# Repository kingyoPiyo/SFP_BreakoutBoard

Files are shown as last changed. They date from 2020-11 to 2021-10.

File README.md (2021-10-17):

# SFP_BreakoutBoard
KiCad とプリント基板発注練習用に作成した SFP 用の Breakout Board です。身近にある Type-C ケーブルから給電可能となるように仕上げてみました。取り付け穴位置は秋月電子のCタイプ基板に揃えているためスタック可能です。  
性能をテストできる機材を持ち合わせていないので信号品質等の詳細はスペック不明ですが、SFP → SMA → SFP 接続時に 1Gbps および 10Gbps で送受信可能なことを確認しています。  
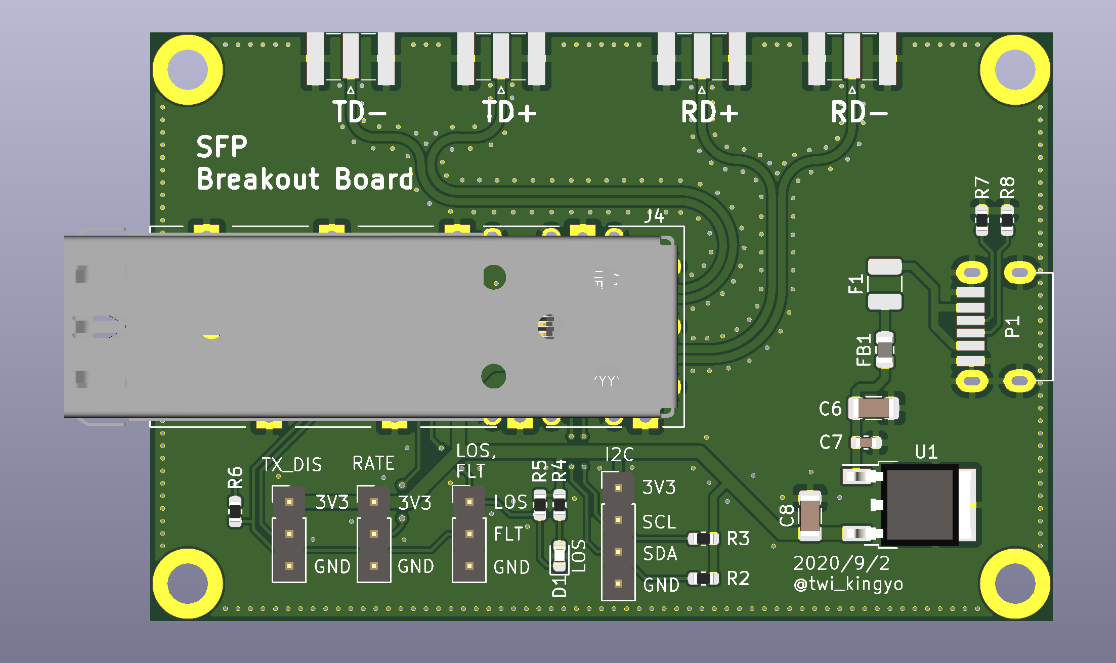
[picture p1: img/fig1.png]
  
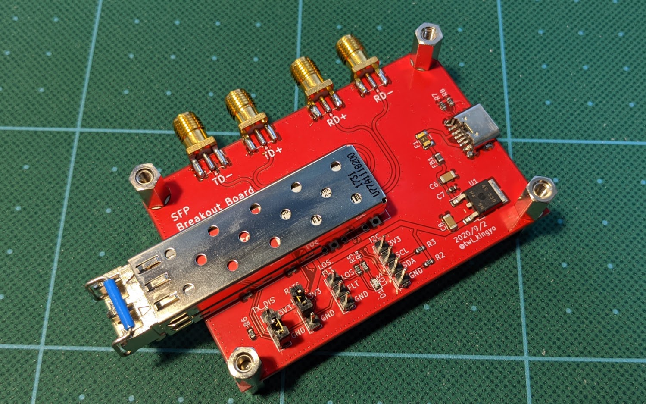
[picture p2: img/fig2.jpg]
  

# 開発環境
- KiCad Version 5.1.6
- RF-tools-KICAD https://github.com/easyw/RF-tools-KiCAD

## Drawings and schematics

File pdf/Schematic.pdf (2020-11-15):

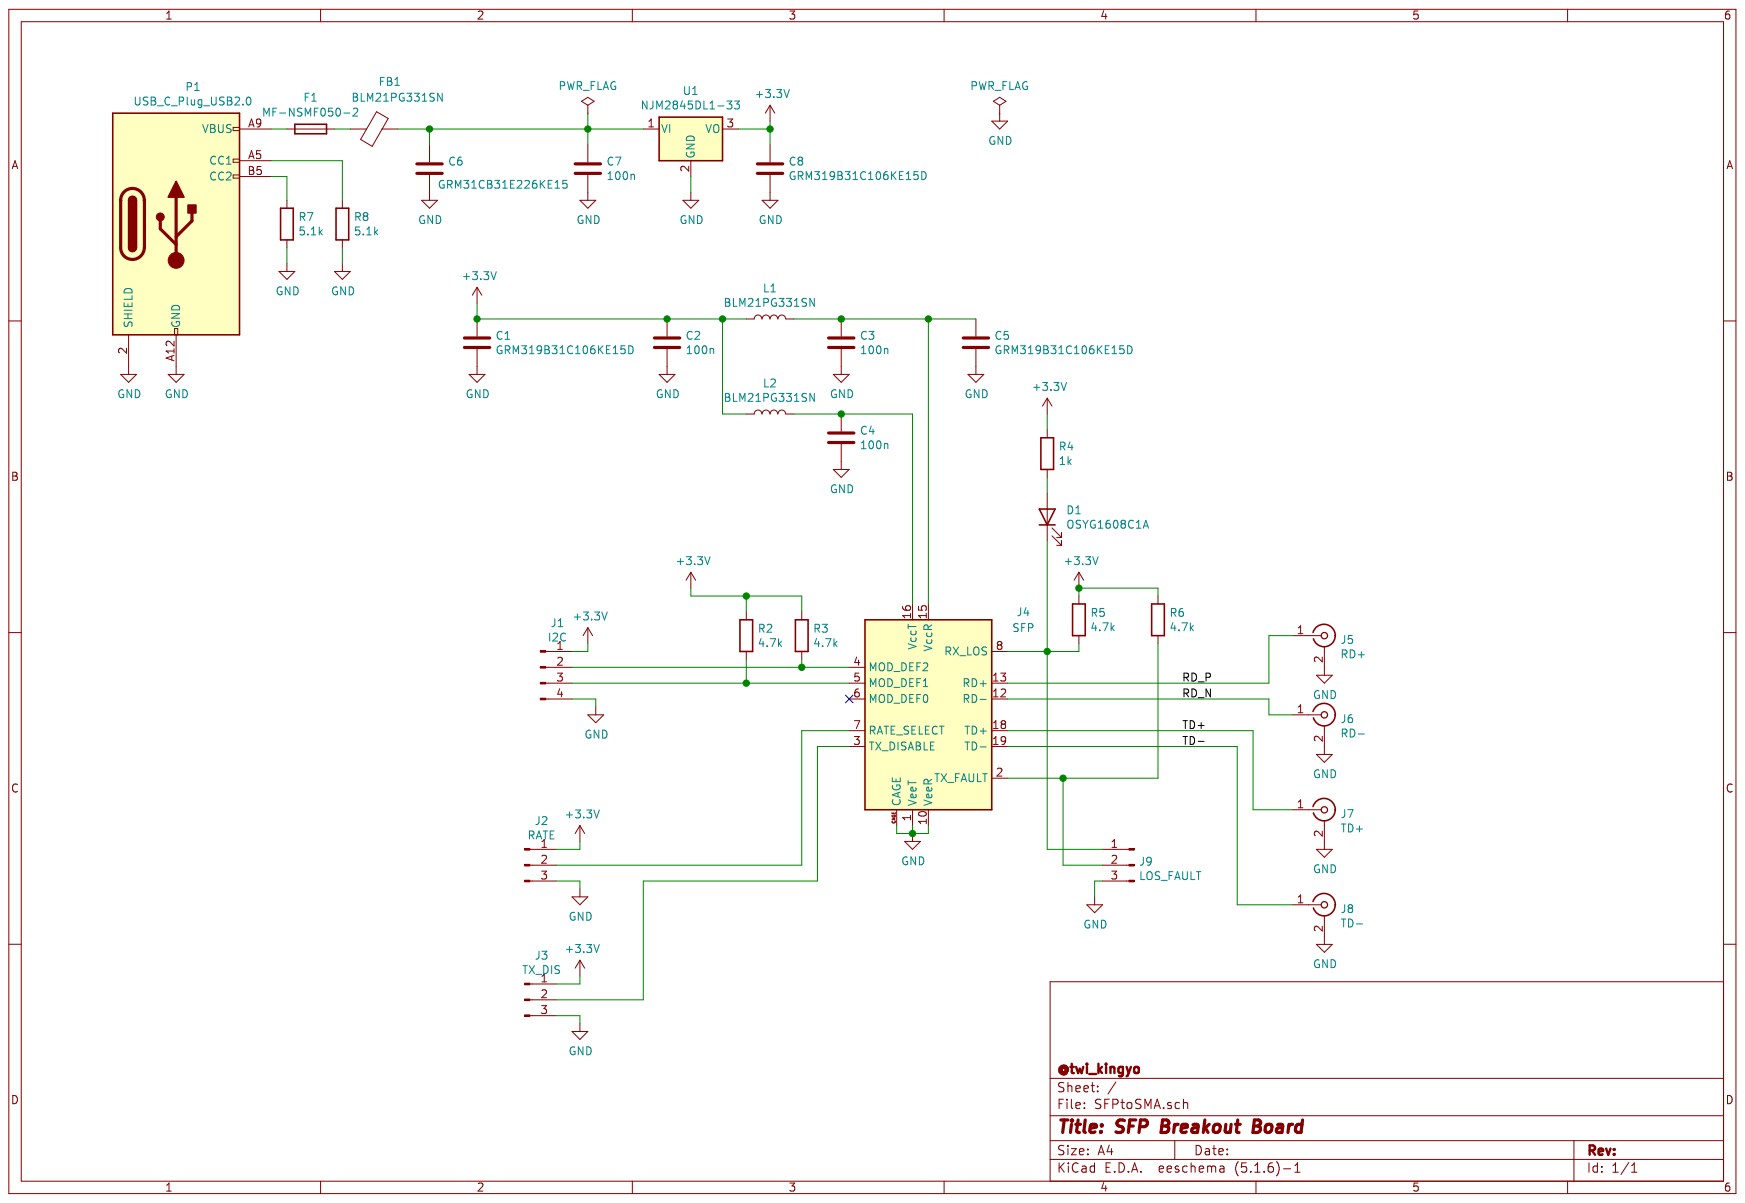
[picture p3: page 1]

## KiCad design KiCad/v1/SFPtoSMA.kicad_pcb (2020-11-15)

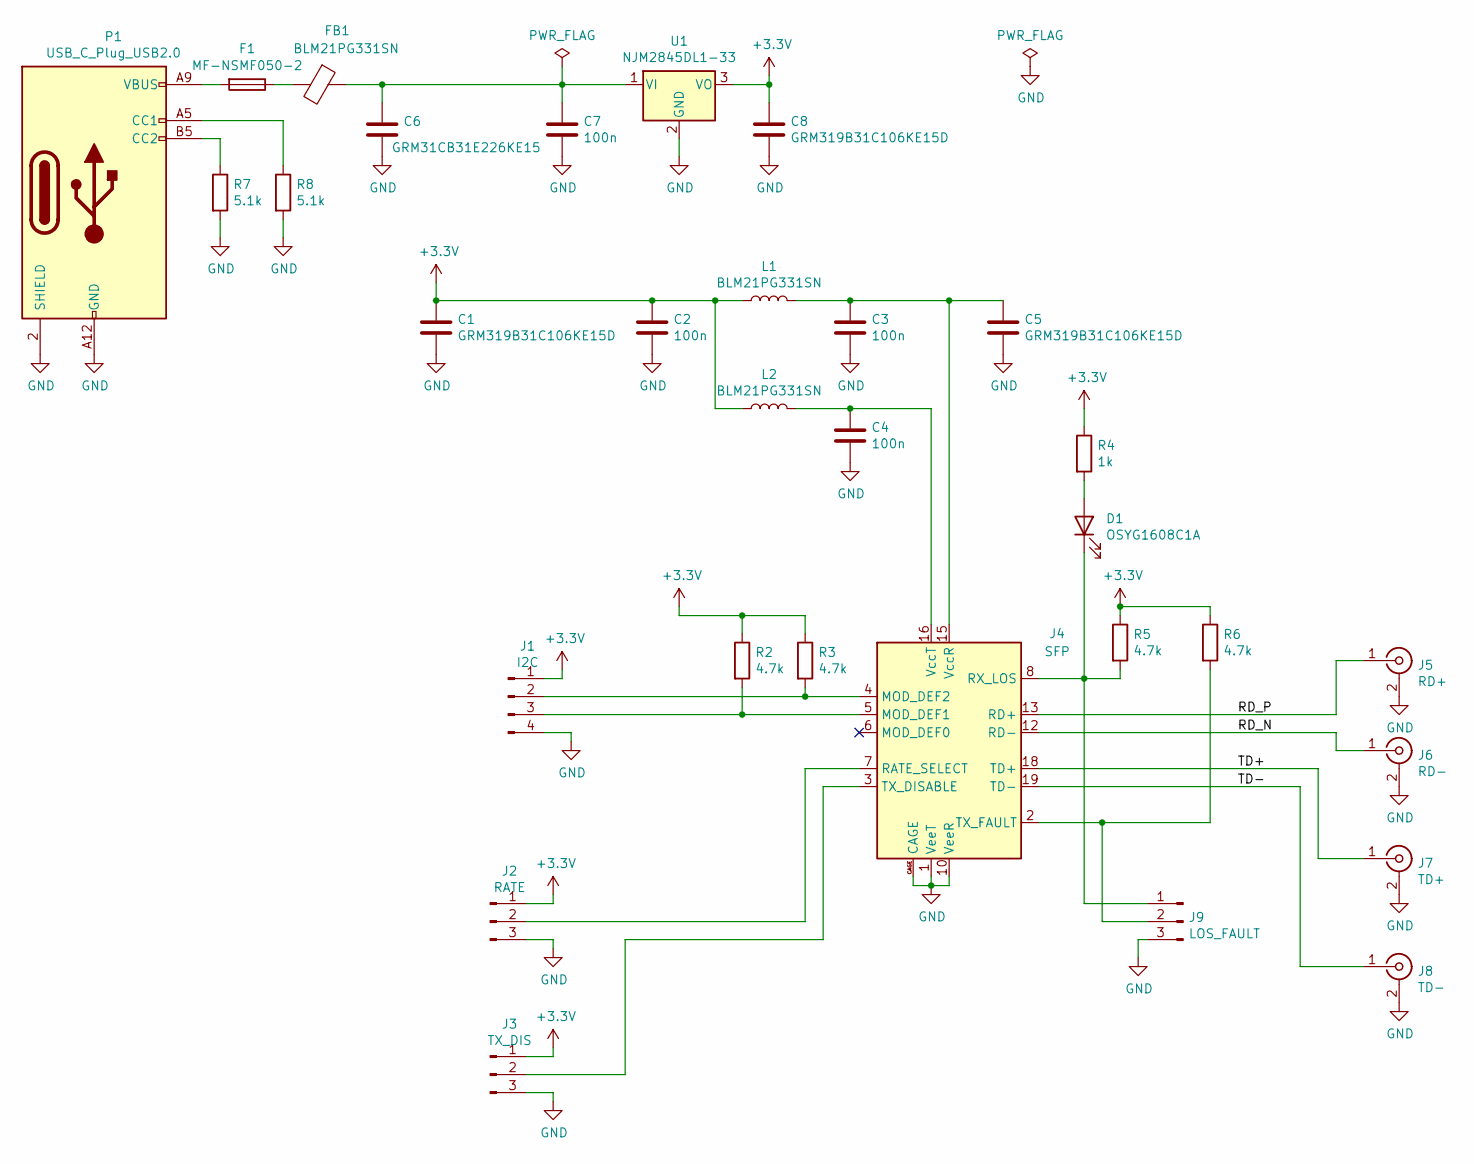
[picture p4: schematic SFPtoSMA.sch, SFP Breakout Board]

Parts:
C1, C5, C8: GRM319B31C106KE15D; C_1206_3216Metric
C2, C3, C4, C7: 100n; C_0603_1608Metric
C6: GRM31CB31E226KE15; C_1206_3216Metric
D1: OSYG1608C1A; LED_0603_1608Metric
F1: MF-NSMF050-2; Fuse_1210_3225Metric
FB1: BLM21PG331SN; L_0805_2012Metric
J1: I2C; PinHeader_1x04_P2.54mm_Vertical
J2: RATE; PinHeader_1x03_P2.54mm_Vertical
J3: TX_DIS; PinHeader_1x03_P2.54mm_Vertical
J4: SFP; Connector_SFP_and_Cage
J5: RD+; SMA_Samtec_SMA-J-P-X-ST-EM1_EdgeMount
J6: RD-; SMA_Samtec_SMA-J-P-X-ST-EM1_EdgeMount
J7: TD+; SMA_Samtec_SMA-J-P-X-ST-EM1_EdgeMount
J8: TD-; SMA_Samtec_SMA-J-P-X-ST-EM1_EdgeMount
J9: LOS_FAULT; PinHeader_1x03_P2.54mm_Vertical
L1, L2: BLM21PG331SN; L_0805_2012Metric
P1: USB_C_Plug_USB2.0; USB-C_Power_only
R2, R3, R5, R6: 4.7k; R_0603_1608Metric
R4: 1k; R_0603_1608Metric
R7, R8: 5.1k; R_0603_1608Metric
U1: NJM2845DL1-33; TO-252-2

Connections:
+3V3: C1.1, C2.1, C8.1, J1.1, J2.1, J3.1, L1.1, L2.1, R2.1, R3.1, R4.1, R5.1, R6.1, U1.3 (VO)
/RD_N: J4.12 (RD-), J6.1 (In)
/RD_P: J4.13 (RD+), J5.1 (In)
/TD+: J4.18 (TD+), J7.1 (In)
/TD-: J4.19 (TD-), J8.1 (In)
GND: C1.2, C2.2, C3.2, C4.2, C5.2, C6.2, C7.2, C8.2, J1.4, J2.3, J3.3, J4.1 (VeeT), J4.9 (VeeR), J4.10 (VeeR), J4.11 (VeeR), J4.14 (VeeR), J4.17 (VeeT), J4.20 (VeeT), J4.CAGE, J5.2 (Ext), J6.2 (Ext), J7.2 (Ext), J8.2 (Ext), J9.3, P1.2 (SHIELD), P1.A12 (GND), P1.B12 (GND), R7.2, R8.2, U1.2 (GND)
unnamed: C3.1, C5.1, J4.15 (VccR), L1.2
unnamed: C4.1, J4.16 (VccT), L2.2
unnamed: C6.1, C7.1, FB1.1, U1.1 (VI)
unnamed: D1.1 (K), J4.8 (RX_LOS), J9.1, R5.2
unnamed: D1.2 (A), R4.2
unnamed: F1.1, FB1.2
unnamed: F1.2, P1.A9 (VBUS), P1.B9 (VBUS)
unnamed: J1.2, J4.4 (MOD_DEF2), R3.2
unnamed: J1.3, J4.5 (MOD_DEF1), R2.2
unnamed: J2.2, J4.7 (RATE_SELECT)
unnamed: J3.2, J4.3 (TX_DISABLE)
unnamed: J4.2 (TX_FAULT), J9.2, R6.2
unnamed: P1.A5 (CC1), R8.1
unnamed: P1.B5 (CC2), R7.1

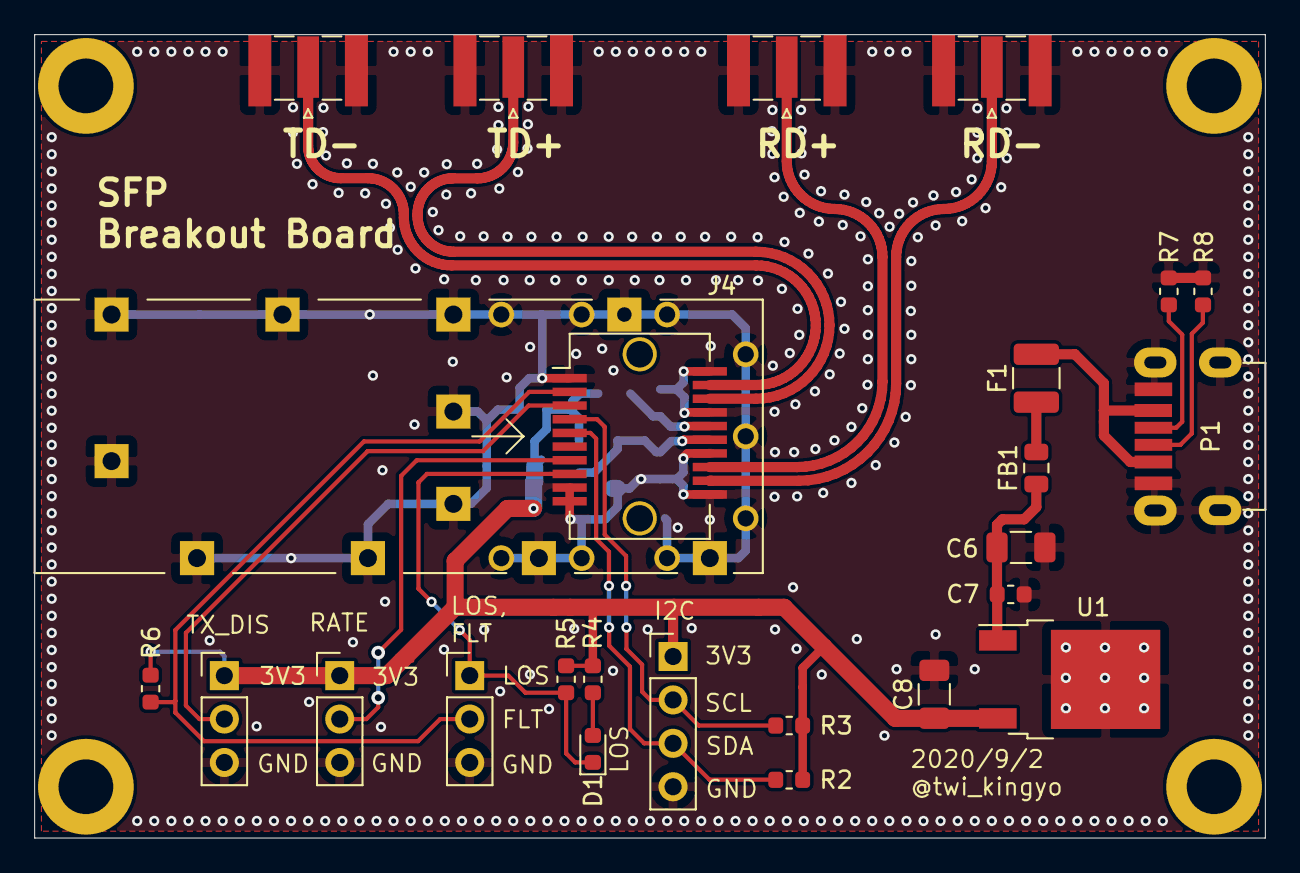
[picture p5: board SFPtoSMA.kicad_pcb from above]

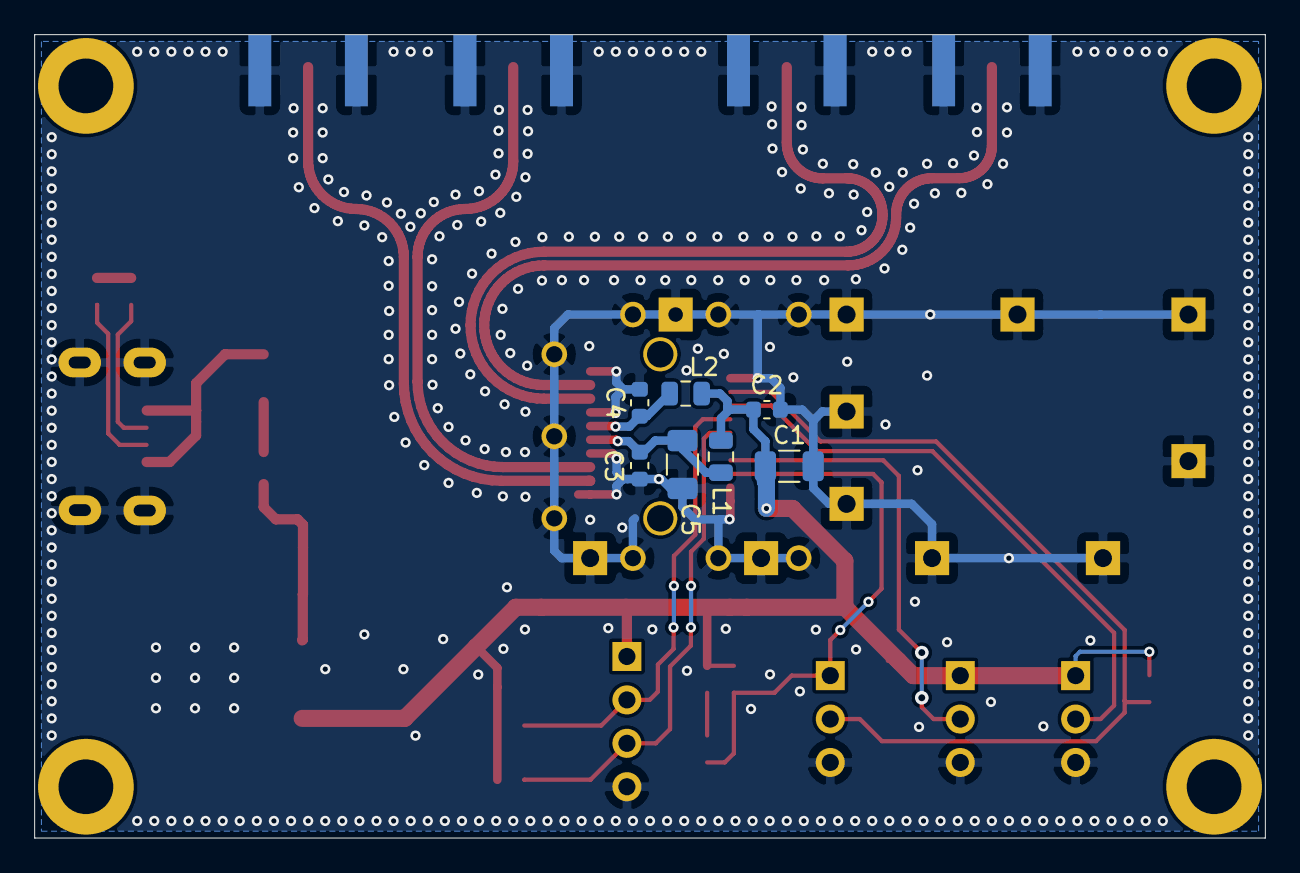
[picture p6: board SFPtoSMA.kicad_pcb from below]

Board: 2 copper layers, 72.0 x 47.0 mm, 31 parts (7 on the bottom side), 20 nets.
